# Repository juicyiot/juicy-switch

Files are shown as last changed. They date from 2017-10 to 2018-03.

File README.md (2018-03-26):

# Juicy Switch :electric_plug::tangerine:



A **RESTful** power **switch**.
The Juicy Switch enables you to turn a 230VAC device **on** and **off** using **HTTP**. E.g. you can switch a :bulb: on by calling `http://juicy.local/on`
and turn it off with `http://juicy.local/off`.

## :warning: Disclaimer :zap:
Mains can kill or severly injure people! Please read about electrical saftey first.
We designed the PCB to the best of our knowledge to be safe (see [Safety](hardware/README.md#safety) and [Enclosure](hardware/Readme.md#enclosure)), however **use it at your own risk**, we are no electrical engineers!

## Design goals
- DIY (do it yourself) :hammer:
- Affordable :dollar:
- Easy to setup and to use (your mom can use it :wink:)
- Simple yet powerful :rocket:

The Juicy Switch can be self assembled and is affordable, see [Bill of Materials](hardware/README.md#bill-of-materials). The setup is a friction less and quick process. After the device is powered up, it will create a WIFI hotspot called `juicy_switch`. Connect with your Smartphone/Notebook and proceed with the one time [Setup](firmware/README.md#usage). Eventhough the switch is very simple to use, many *smart* use cases can be built on top, see [Use Case Ideas](#use-case-ideas) to get inspired.

## Hardware
Head over to the dedicated [Hardware-Readme](hardware/README.md#setup)

## Software
Head over to the dedicated [Firmaware-Readme](firmware/README.md#setup)

## Progress/Status
October 2017: PCB got produced and has been shipped.
January 2018: PCB soldered but found an issue

## Use Case Ideas
- Calendar
- IFTTT
- Google Home

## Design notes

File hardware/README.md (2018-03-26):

# Juicy Switch Hardware :electric_plug::tangerine:

## :warning: Disclaimer :zap:
Mains can kill or severly injure people! Please read about electrical saftey first.
We designed the PCB to the best of our knowledge to be safe (see [Safety](#safety) and [Enclosure](#enclosure)), however **use it at your own risk**, we are no electrical engineers!

## Hardware

OSH Open Source Hardware

### Bill of Materials

The cost per unit is roughly 10$.

| Marking    | Item             | Package           | Value         |
------------ | ---------------- |------------------ | ------------- |
|            | µC-ESP826 ESP-07 | -                 | -             |
|            | HLK-PM01         | -                 | -             |
| R1,R2,R6,R8| resistor         | SMD 0815          | 10kΩ          |
| R3,R4      | resistor         | SMD 0815          | 1kΩ           |
| R5         | resistor         | SMD 0815          | 120Ω          |
| R7         | varistor         | THT               | 250VAC/2500A  |
| C1         | capacitor        | SMD 0815          | 22µF          |
| C2,C4      | capacitor        | SMD 0815          | 10µF          |
| C3         | capacitor        | SMD               | 100µF         |
| C5,C6      | capactior        | SMD 0815          | 100nF         |
| J3,J5      | screw terminal   | THT               | 5m            |
| D1,D3      | LED              | THT               | 3mm           |
| D2         | diode 1n4148     | THT               | 200mA/100V/1V |
| F1         | fuse (slow blow) | glass tube 5x20mm | 0.3A          |
| F2         | fuse (fast blow) | glass tube 5x20mm | 6.3A          |
| F1,F2      | fuse holder      | THT 5x20mm        | -             |
| Q1         | transistor npn   | SMD SOT23-3       | 0.5A/40V      |
| K1         | relay            | -                 | 10A/250VAC    |
| U1         | voltage regulator| SOT23-3           | 3.3V          |
| S1         | tactile switch   | SMD (4x4x1.5mm)   | -             |
| J1,J2,J4,J6 | Headers         | THT               | -             |

#### Schematic
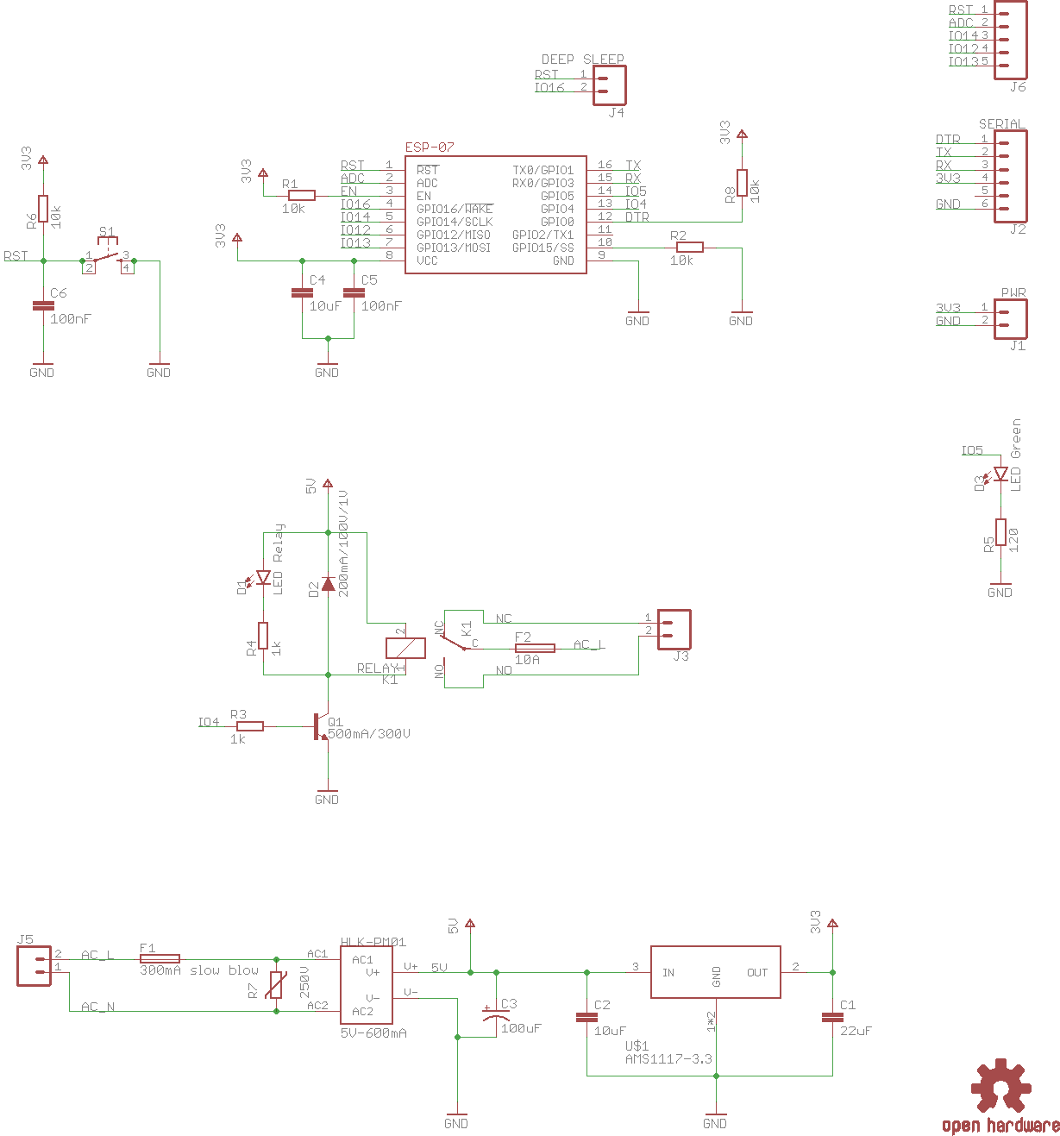
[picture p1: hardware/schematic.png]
Schematic


#### Board
Seeedstudio manufactured our board (2 layer and 1oz of copper).

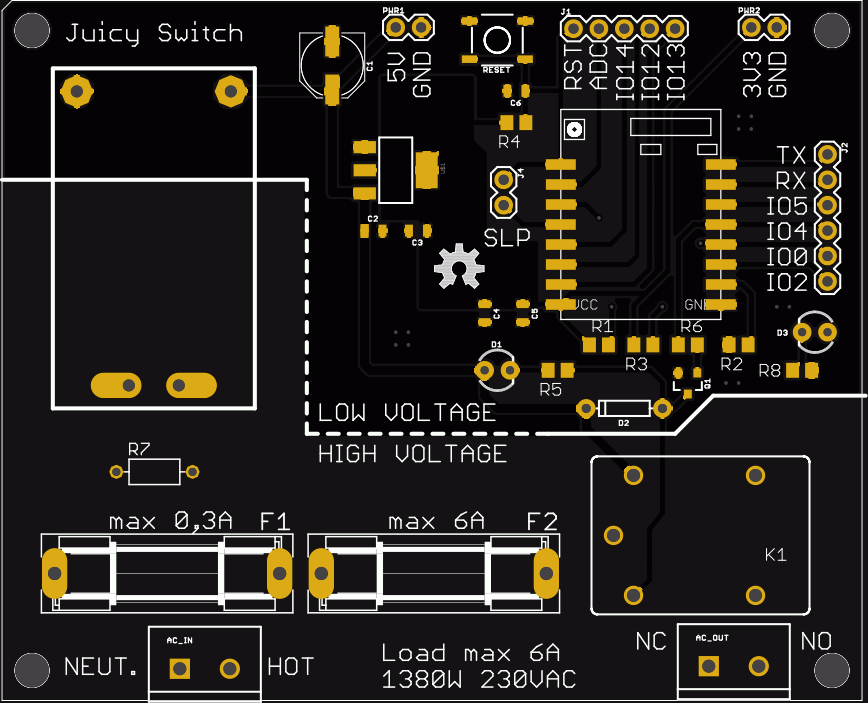
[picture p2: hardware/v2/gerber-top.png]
Gerber view top

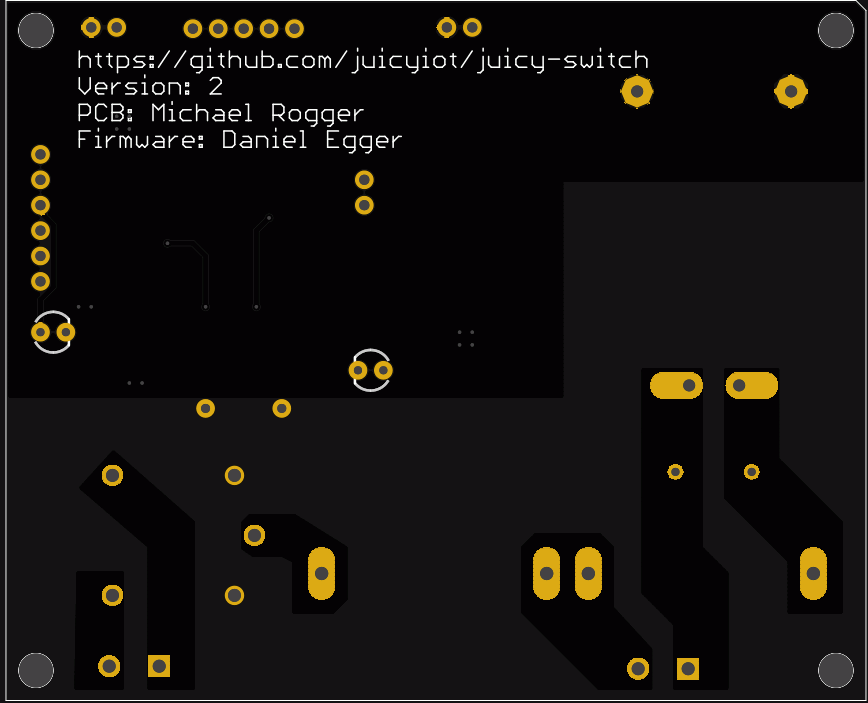
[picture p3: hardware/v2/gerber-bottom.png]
Gerber view bottom


### Assembly
- Solder the ESP and related resistors/capcitors.
- Flash the ESP with a bootloader, upload our sketch and verify it is correctly running.
- Solder the power supply and the related fuse/varistor.
- Solder the relay and related fuse.

### Enclosure
The PCB **must** be enclosed by a **plastic** box. Use **non conducting** materials, e.g. plastic standoffs. The box should be kept in a dry environment (inside). Do not open the box while connected to mains, always unplug first.

### Sources
- https://esp8266.github.io/Arduino/versions/2.3.0/doc/boards.html
- http://www.learnabout-electronics.org/PSU/psu10.php
- http://circuitcalculator.com/wordpress/2006/01/31/pcb-trace-width-calculator/
- http://lygte-info.dk/review/Power%20Mains%20to%205V%200.6A%20Hi-Link%20HLK-PM01%20UK.html
- https://forum.mysensors.org/topic/1607/safe-in-wall-ac-to-dc-transformers
- http://www.reo.co.uk/files/safety_7_-_low_voltage_directive.pdf
- http://creepage.com/

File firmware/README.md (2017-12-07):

# Juicy Switch Firmware 🔌 🍊 💻



⚠️ **This is work in progress!** ⚠️

The firmware powering Juicy's *esp* chip. It lets you configure the WiFi that Juicy should connect to and provides a RESTful API for controlling the chip's LED. Later, when Juicy is fully assembled, you will be able to power the switch on and off via that API.

## Features

The following is a rough outline of features we want to implement. Already implemented features are marked accordingly.

- [x] Easy configuration of Juicy's WiFi connection
- [x] Configuration via a captive portal (tested on iOS)
- [x] Persisted WiFi credentials
- [x] Auto connect if correct WiFi credentials are available
- [x] LED feedback on successful or failed WiFi configuration
- [x] MDNS hostname for the API endpoint
- [ ] Automatic reconnection if WiFi connection is lost
- [ ] Nice looking configuration interface
- [ ] Unique API hostname
- [ ] WiFi scan for an easier configuration process
- [ ] ...

## Getting Started

### Development & Installation

The easiest way to get the Juicy firmware up and running on your esp chip is using the [*PlatformIO IDE*](http://platformio.org/get-started/ide) or [*PlatformIO Core*](http://platformio.org/get-started/cli).

[Here](http://docs.platformio.org/en/latest/ide/atom.html#quick-start) you can find instructions on how to setup PlatformIO IDE for [Atom](https://atom.io). Just import Juicy's `/firmware` directory as a project and you're ready to go.

### Usage

Assuming you have just flashed the firmware onto your esp chip and not connected it to your WiFi before you can use your phone or another WiFi enabled device to configure the chip:

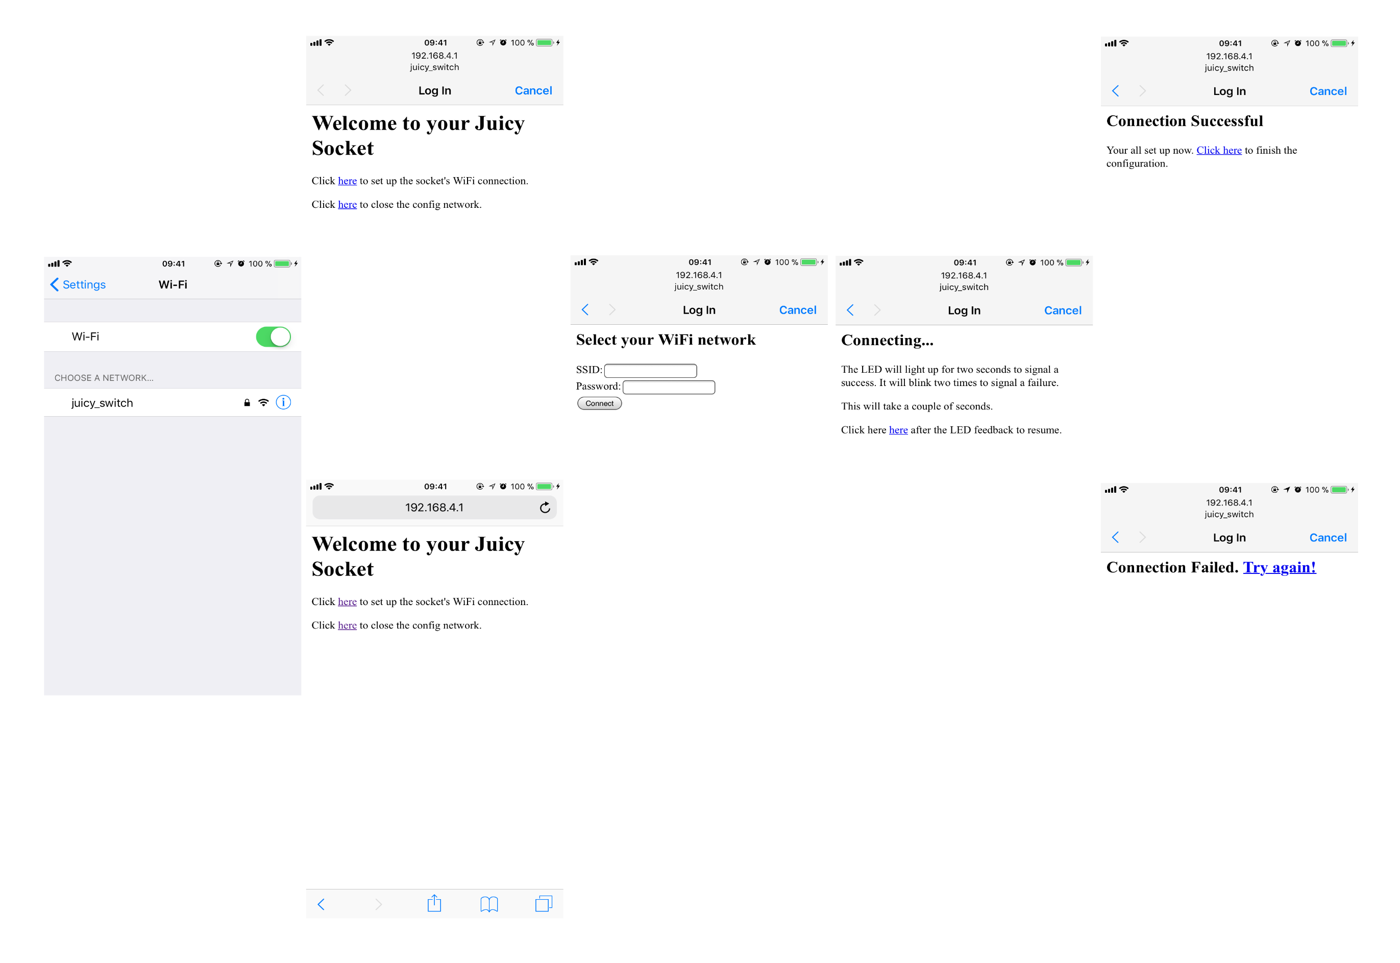
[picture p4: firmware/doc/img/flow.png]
Configuration flow Juciy coniguration flow


1. Make sure the chip is powered on.
2. Connect to the Juicy configuration network (`juicy_switch`) using your phone or another device.
3. Once you connected to the Juicy configuration network, a captive portal dialogue displaying the Juicy configuration page may appear.

	- *Note:* If the captive portal dialogue does not appear, you can just use your browser when connected to the Juicy configuration network and point it to `192.168.4.1` to start the configuration process. If you don't like typing IP's, just go to any website when connected to the Juicy configuration network (e.g. `example.com`) and you will be redirected to the configuration page.

4. You should now see the Juicy configuration page.
5. Follow the instructions on the Juicy configuration page.
6. Type in the credentials of your WiFi network.
7. Wait for the LED feedback on your chip.

	- If the chip cannot connect to your WiFi, the LED will blink two times.
	- If the chip successfully connected to your WiFi, the LED will light up continuously for two seconds.

8. Follow the instructions on the Juicy configuration page. If the connection failed, you'll be given a link to retype the credentials of your WiFi. If the connection succeeded, you'll be given a link to finish the configuration process.
9. Once you finished the configuration process, your chip will be connected to your WiFi and the Juicy configuration network will be closed.

Congratulations, Juicy is now setup and ready to go. You can use *[nmap](https://nmap.org)* to find out it's IP or just access it via `juicy_switch.local`. It's recommended to use the IP directly since it seems to be faster.

You can also shut down your chip now. If you power it up again it will remember your WiFi network's credentials and automatically connect to it on startup. If you change your WiFi credentials, just restart the chip. It will notice that the old credentials do not work anymore and reopen the Juicy configuration network for you to provide the new credentials.

**Note:** Your WiFi's credentials will be stored on the esp chip in *plain text* (unencrypted). 

### API

#### Configure and Setup

``` c++
// Create an API instance with a certain hostname.
API api("juicy_hostname");
	
// Add a PIN that will be toggled by the API.
// The first parameter is the pin.
// The second parameter is the ON value.
// The second parameter is the OFF value.
api.addPin(LED_BUILTIN, LOW, HIGH);
	
// After adding all desired pins, stup the API.
api.setup();
	
/* Later on in your main loop() */
	
// Serve the API.
api.serve();
```

#### Endpoints

The API serves the following endpoints:

``` shell
# Writes the previously specified ON value to all added pins.
curl juicy_switch.local/on

# Writes the previously specified OFF value to all added pins.
curl juicy_switch.local/off

# Returns a JSON containing a `status` value that is either:
# - `on` if all pins are on
# - `off` if all pins are off
# - `undefined` if no common pin status could be determined.
curl juicy_switch.local/status
```

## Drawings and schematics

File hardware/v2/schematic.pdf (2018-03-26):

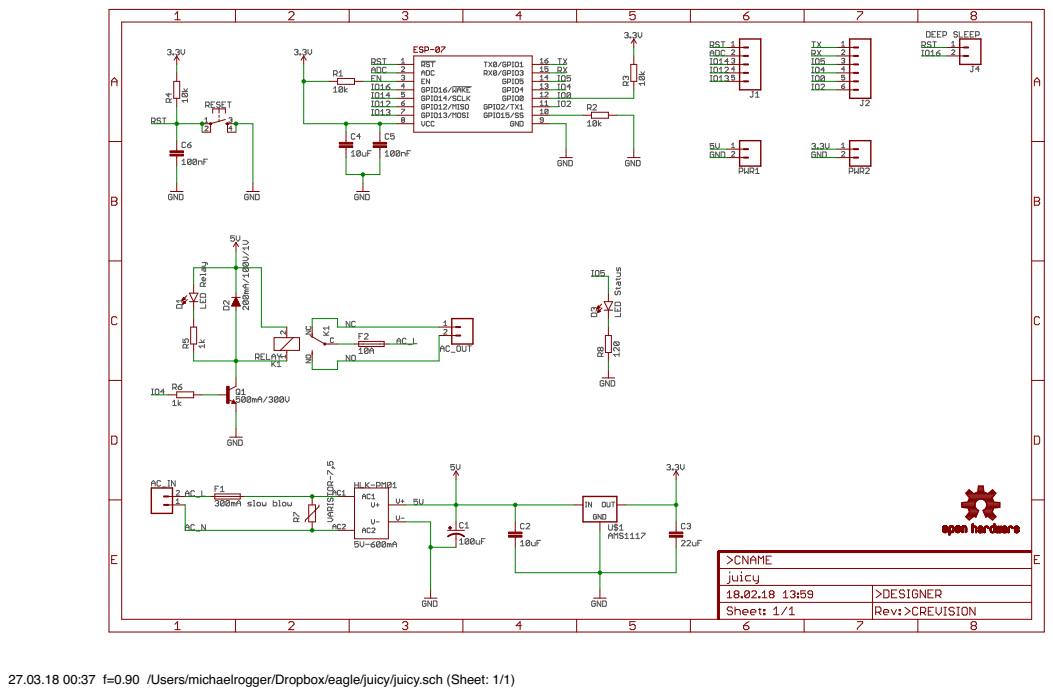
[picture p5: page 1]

27.03.18 00:37 f=0.90 /Users/michaelrogger/Dropbox/eagle/juicy/juicy.sch (Sheet: 1/1)

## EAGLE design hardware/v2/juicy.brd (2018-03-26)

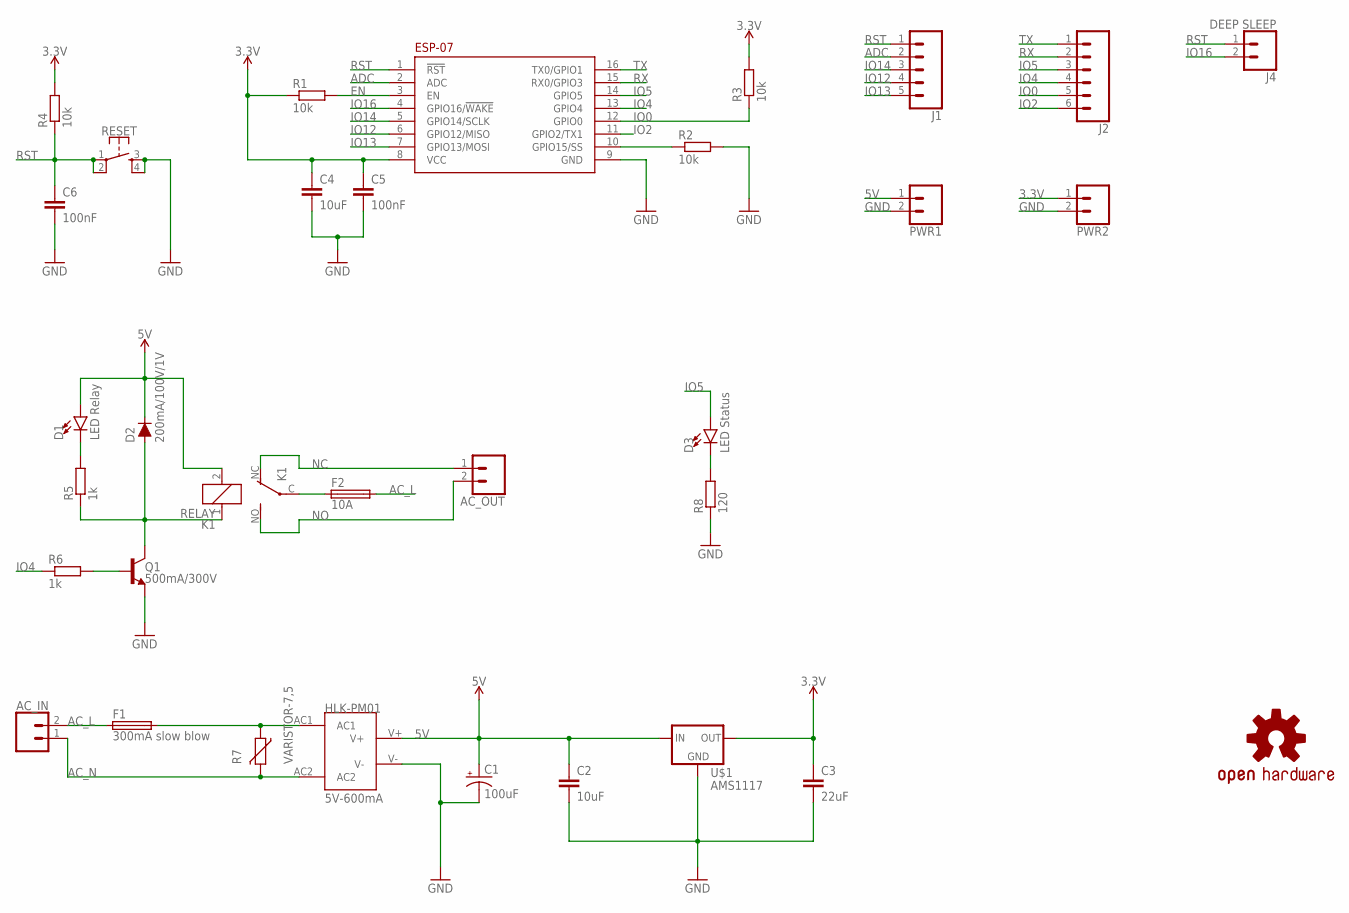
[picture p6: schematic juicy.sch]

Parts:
AC_IN: CONN_025MM; SCREWTERMINAL-5MM-2
AC_OUT: CONN_025MM; SCREWTERMINAL-5MM-2
C1: 100uF; PANASONIC_D
C2, C4: 10uF; 0805
C3: 22uF; 0805
C5, C6: 100nF; 0805
D1: LED Relay; LED_3MM
D2: 200mA/100V/1V; DIODE-1N4148
D3: LED Status; LED_3MM
F1: 300mA slow blow; SH22,5
F2: 10A; SH22,5
J1: CONN_05; 1X05
J2: CONN_06SILK_FEMALE_PTH; 1X06
J4: DEEP SLEEP; 1X02
K1: RELAY; JS-M
LOGO1: OSHW-LOGOM; OSHW-LOGO-M
PWR1, PWR2: CONN_02; 1X02
Q1: 500mA/300V; SOT23-3
R1, R2, R3, R4: 10k; R0805
R5, R6: 1k; R0805
R7: VARISTOR-7,5; R-7,5
R8: 120; R0805
RESET: MOMENTARY-SWITCH-SPST-2-SMD-5.2MM; TACTILE_SWITCH_SMD_5.2MM
U$1: AMS1117; SOT223
U$2: ESP8266
U$3: HILINK; HLK-PM01

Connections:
3.3V: C3.1, C4.1, C5.1, PWR2.1, R1.1, R3.2, R4.2, U$1.2 (OUT), U$1.4 (OUT), U$2.8 (VCC)
5V: C1.+, C2.1, D1.A, D2.C, K1.2, PWR1.1, U$1.3 (IN), U$3.V+
AC1: F1.2, R7.1, U$3.AC1
AC_L: AC_IN.2, F1.1, F2.2
AC_N: AC_IN.1, R7.2, U$3.AC2
ADC: J1.2, U$2.2 (ADC)
EN: R1.2, U$2.3 (EN)
GND: C1.-, C2.2, C3.2, C4.2, C5.2, C6.2, PWR1.2, PWR2.2, Q1.2 (E), R2.2, R8.1, RESET.3, RESET.4, U$1.1 (GND), U$2.9 (GND), U$3.V-
IO0: J2.5, R3.1, U$2.12 (GPIO0)
IO2: J2.6, U$2.11 (GPIO2/TX1)
IO4: J2.4, R6.1, U$2.13 (GPIO4)
IO5: D3.A, J2.3, U$2.14 (GPIO5)
IO12: J1.4, U$2.6 (GPIO12/MISO)
IO13: J1.5, U$2.7 (GPIO13/MOSI)
IO14: J1.3, U$2.5 (GPIO14/SCLK)
IO16: J4.2, U$2.4 (GPIO16/!WAKE!)
unnamed: F2.1, K1.C
unnamed: R2.1, U$2.10 (GPIO15/SS)
unnamed: D2.A, K1.1, Q1.3 (C), R5.1
unnamed: D3.K (C), R8.2
unnamed: D1.K (C), R5.2
unnamed: Q1.1 (B), R6.2
NC: AC_OUT.1, K1.NC (O)
NO: AC_OUT.2, K1.NO (S)
RST: C6.1, J1.1, J4.1, R4.1, RESET.1, RESET.2, U$2.1 (!RST!)
RX: J2.2, U$2.15 (RX0/GPIO3)
TX: J2.1, U$2.16 (TX0/GPIO1)

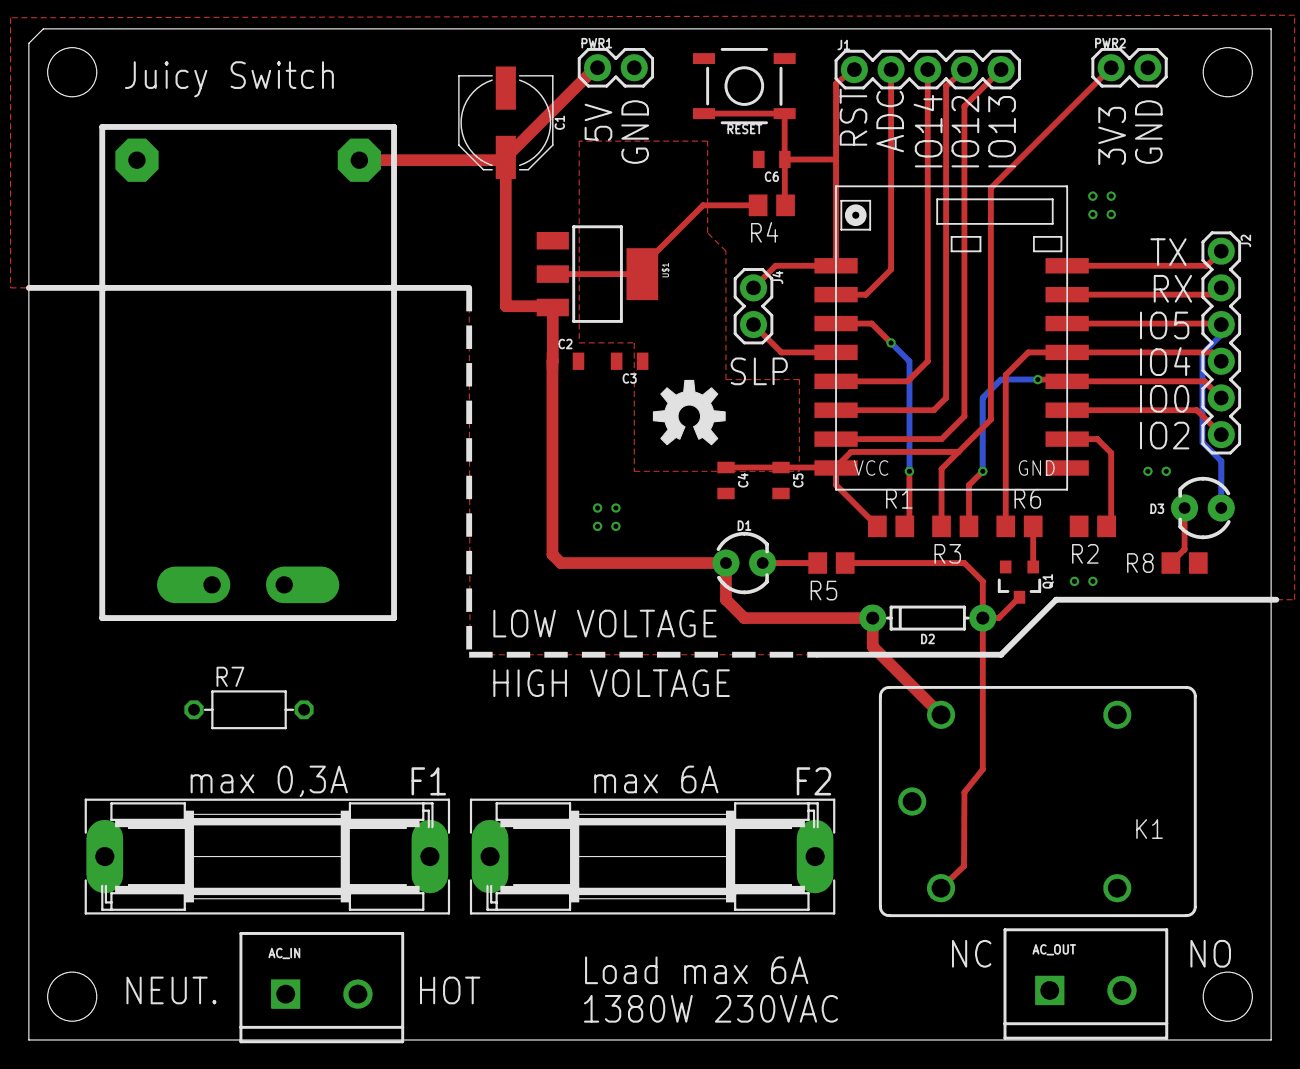
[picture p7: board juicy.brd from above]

Board: 2 copper layers, 86.0 x 70.0 mm, 33 parts (0 on the bottom side), 27 nets.

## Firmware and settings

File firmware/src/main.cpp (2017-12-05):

#include <Arduino.h>
#include "WiFi/WiFiConnection.h"
#include "Config/ConfigServer.h"
#include "API/API.h"

const char *CONFIG_NET_SSID = "juicy_switch";
const char *CONFIG_NET_PASS = "password";
const char *API_HOST = "juicy_switch";

ConfigServer config(CONFIG_NET_SSID, CONFIG_NET_PASS);
WiFiConnection connection;
API api(API_HOST);

void setup() {
    Serial.begin(115200);
	delay(3000);

	// Try to connect using persisted credentials.
	// If the connection failes, setup a configuration AP
	// that blocks until new credentials have been provided
	// and we are successfully connected to the local network.
	if (!connection.connect()) {
		config.setup();
		config.run();
	}

	Serial.print("Connected to " + connection.getSSID() + ". Local IP: " + connection.getIP());

	api.addPin(LED_BUILTIN, LOW, HIGH);
	api.setup();
}

void loop() {
	api.serve();
}

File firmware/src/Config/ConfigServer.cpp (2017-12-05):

#include "ConfigServer.h"

#include "../WiFi/WiFiConnection.h"

const IPAddress AP_IP(192, 168, 4, 1);
const IPAddress AP_NM(255, 255, 255, 0);

const int PORT_WEB = 80;
const int PORT_DNS = 53;

ConfigServer::ConfigServer(const char *ssid, const char *password) {
	configNetSSID = ssid;
	configNetPass = password;

	status = none;
	shouldConnect = false;

	connectionSuccessCallback = []() {
		pinMode(LED_BUILTIN, OUTPUT);
		digitalWrite(LED_BUILTIN, HIGH);

		digitalWrite(LED_BUILTIN, LOW);
		delay(2000);
		digitalWrite(LED_BUILTIN, HIGH);
	};

	connectionFailureCallback = []() {
		pinMode(LED_BUILTIN, OUTPUT);
		digitalWrite(LED_BUILTIN, HIGH);

		for (int i = 0; i < 2; i++) {
			digitalWrite(LED_BUILTIN, LOW);
			delay(500);
			digitalWrite(LED_BUILTIN, HIGH);
			delay(500);
		}
	};
}

void ConfigServer::setup() {
	WiFi.mode(WIFI_AP_STA);

	webServer.reset(new ESP8266WebServer(PORT_WEB));
	dnsServer.reset(new DNSServer());

	WiFi.softAPConfig(AP_IP, AP_IP, AP_NM);
	WiFi.softAP(configNetSSID, configNetPass);

	delay(500);

	dnsServer->setErrorReplyCode(DNSReplyCode::NoError);
	dnsServer->start(PORT_DNS, "*", WiFi.softAPIP());

	HttpHandler handler(webServer, *this);
	webServer->on("/", std::bind(&HttpHandler::handleRoot, handler));
	webServer->on("/setup", std::bind(&HttpHandler::handleSetup, handler));
	webServer->on("/save", std::bind(&HttpHandler::handleSave, handler));
	webServer->on("/status", std::bind(&HttpHandler::handleStatus, handler));
	webServer->on("/close", std::bind(&HttpHandler::handleClose, handler));
	webServer->onNotFound(std::bind(&HttpHandler::handleNotFound, handler));
	webServer->begin();
}

void ConfigServer::run() {
	while (status != done) {
		dnsServer->processNextRequest();
		webServer->handleClient();

		if (shouldConnect) {
			shouldConnect = false;

			status = connectToNetwork() ? successful : failed;

			if (status == successful) {
				connectionSuccessCallback();
			} else {
				connectionFailureCallback();
			}
		}
	}

	webServer.reset();
	dnsServer.reset();
}

bool ConfigServer::connectToNetwork() {
	WiFiConnection connection(networkCredentials.ssid, networkCredentials.password);

	if (connection.connect()) {
		connection.persistCredentials();

		return true;
	}

	return false;
}

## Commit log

2017-10-28 Add bill of materials and schematic/board (#2)
    * Add bill of materials and schematic/board
    * Fix typo
2018-03-26 Add source files
    [juicy.GBL, juicy.GBO, juicy.GBP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]

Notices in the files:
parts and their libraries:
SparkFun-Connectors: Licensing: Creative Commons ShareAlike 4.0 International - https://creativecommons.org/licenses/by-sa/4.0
